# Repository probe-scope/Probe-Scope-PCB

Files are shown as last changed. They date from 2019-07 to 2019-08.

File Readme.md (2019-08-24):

# Probe-Scope PCB

This is the repo for the Probe-Scope, it is licenced under the CERN Open Hardware Licence v1.2.

See more on our [project page!](https://hackaday.io/project/165964-60mhz-bandwidth-250msps-probe-scope)

# Schematic Overview

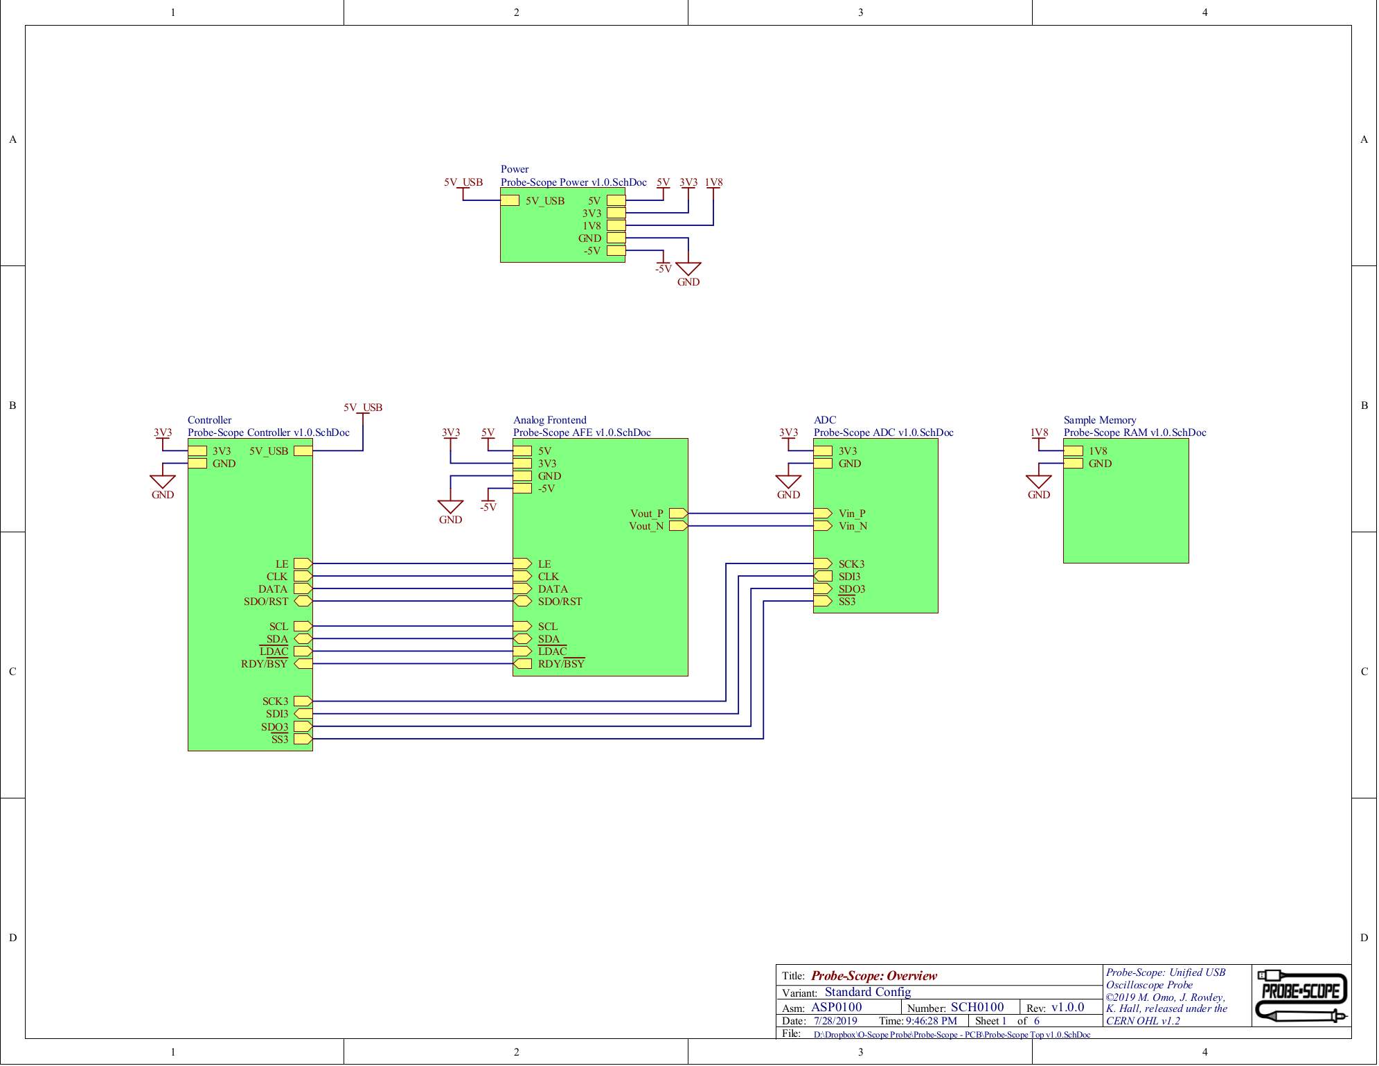
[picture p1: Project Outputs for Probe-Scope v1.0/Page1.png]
Page 1


# Final Assembled PCB

## Top

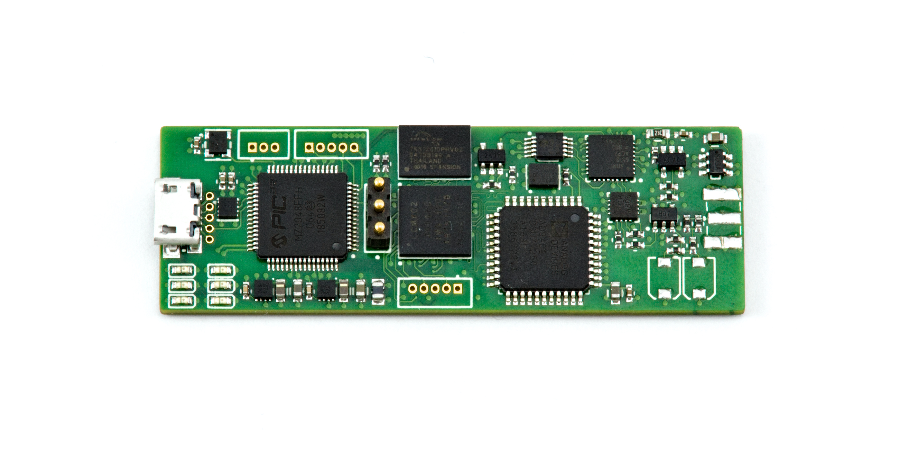
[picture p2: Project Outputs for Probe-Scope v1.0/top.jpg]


## Bottom

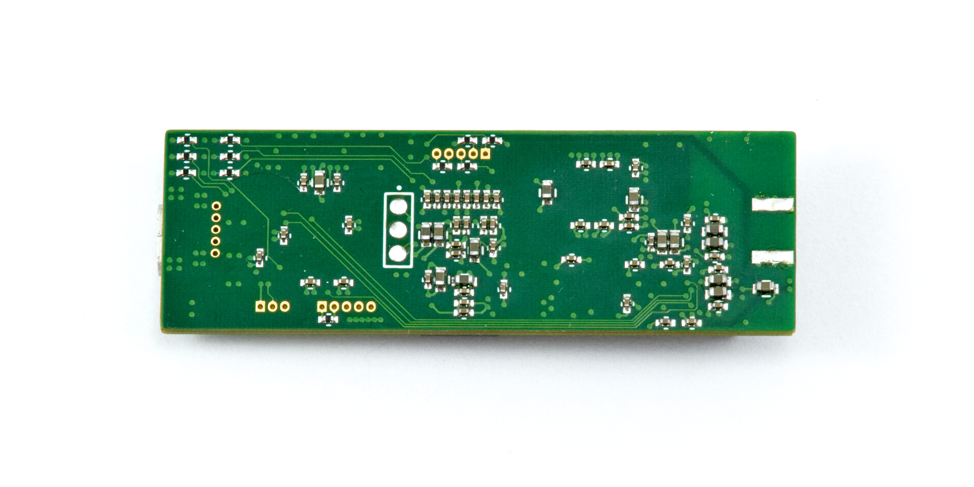
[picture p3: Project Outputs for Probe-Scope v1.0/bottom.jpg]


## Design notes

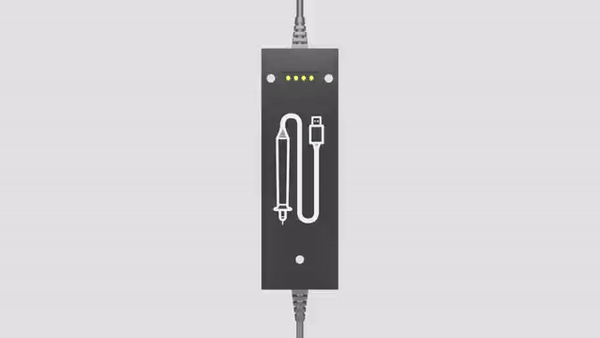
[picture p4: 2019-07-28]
Concept GIF.gif

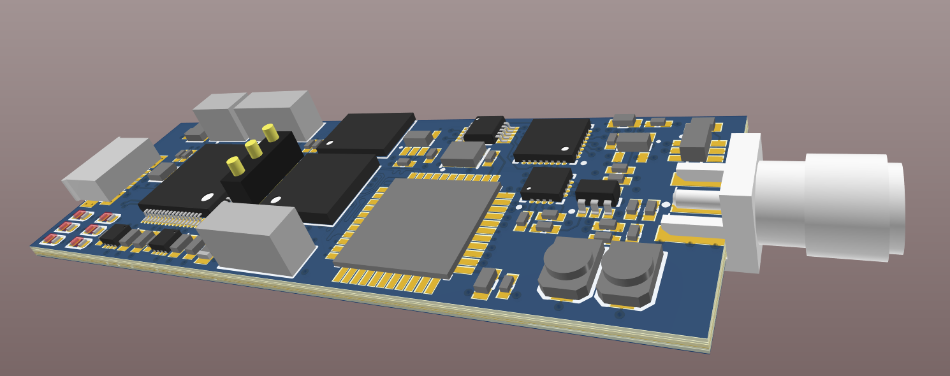
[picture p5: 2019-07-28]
3D Picture.PNG

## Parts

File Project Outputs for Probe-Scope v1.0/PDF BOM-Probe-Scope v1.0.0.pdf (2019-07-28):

BILL OF MATERIALS | Probe-Scope: Unified USB Oscilloscope Probe ©2019 M. Omo, J. Rowley, K. Hall Released under the CERN OHL v1.2
Designator | MANF | MANF_PN | Quantity | VENDOR | VENDOR_PN | P&V Description | Footprint | Comment
C1, C2, C3, C4, C5, C6, C7, C8, C9, C10, C11, C13, C14, C15, C16, C17, C18, C19, C20, C21, C22, C23, C26, C31, C32, C33, C34, C35, C36, C38, C40, C41, C42, C43, C44, C45, C46, C47, C48, C50, C51, C52, C54, C55, C56, C58, C59, C60, C64, C65, C66 | Samsung Electro-Mechanics | CL05B104KQ5NNNC | 51 | Digikey | 1276-1511-1-ND | Capacitor, Ceramic, 0.1uF, 6.3V, 10% Tol, 125C, X7R, 0402, SMD | 0402(1005) | 6.3V
C12 | Murata Electronics | GCM155C71A105KE38D | 1 | Digikey | 490-13409-1-ND | Capacitor, Ceramic, 1uF, 10V, 10% Tol, 125C, X7S, 0402, SMD | 0402(1005) | 10V
C24, C25, C27, C28, C29, C30, C37, C39, C49, C53, C57, C61, C62, C63, C67, C68, C70, C72, C73 | Samsung Electro-Mechanics | CL10A106MA8NRNC | 19 | Digikey | 1276-1869-1-ND | Capacitor, Ceramic, 10uF, 25V, 20% Tol, 85C, X5R, 0603, SMD | 0603(1608) | 25V
C69, C71 | Samsung Electro-Mechanics | CL05B561KB5NNNC | 2 | Digikey | 1276-1577-1-ND | Capacitor, Electrolytic, 560p, 50V, 10% Tol, 0402, SMD | 0402(1005) | Cap
D1, D2, D3, D5, D6, D7 | OSRAM | LG L29K-F2J1-24 | 6 | Digikey | 475-1193-1-ND | LED, 1.7V, 0.02A, Green, 570nm, diffused, 0603, SMD | 0603(1608) LED | Green
L1, L2 | Taiyo Yuden | MCKK1608T1R0MN | 2 | Digikey | 587-5973-1-ND | Inductor, Shielded, 1u, 1.3A, 0.123 Ohms, 0603, SMD | 0603(1608) | Inductor
L3 | TDK | MMZ2012Y121B | 1 | Digikey | 445-2196-1-ND | Inductor, Ferrite Bead, 0.8A, 120 Ohm at 100MHz, Effective from 80MHz To 400MHz, Y Material, 0805, SMD | 0805(2012) | Ferrite Bead Y
P3 | Amphenol FCI | 10118192-0002LF | 1 | Digikey | 609-5379-1-ND | Connector, USB, 5 Positions, Female, 0.026" Spacing, 1.8A, 100V, USB - micro B USB 2.0 Receptacle Connector 5 Position Surface Mount, Right Angle, Without Flange, SMD | USB Micro B ZX62 | Micro USB
P7 | Prec-Dip | 811-SS-003-30-002101 | 1 | DigiKey | 1212-1561-ND | | POGO_PIN S_3 | Pogo Pins
R1, R4, R5, R6, R9, R10, R11 | Yageo | RC0402FR-07100RL | 7 | Digikey | 311-100LRCT-ND | Resistor, Thick Film, 100 Ohms, 0.0625W, 1% Tol, 100V, 0402, SMD | 0402(1005) | Res1
R2, R3, R7 | Stackpole Electronics | RMCF0402FT10K0 | 3 | Digikey | RMCF0402FT10K0CT-ND | Resistor, Thick Film, 10k Ohms, 0.0625W, 1% Tol, 100V, 0402, SMD | 0402(1005) | 0.1% 25ppm
R8 | Panasonic | ERJ-3EKF1692V | 1 | Digikey | P16.9KHCT-ND | Resistor, Thick Film, 16.9k Ohms, 0.1W, 1% Tol, 0603, SMD | 0603(1608) | Res1
R12, R13, R14, R15 | Yageo | RC0402FR-074K99L | 4 | Digikey | 311-4.99KLRCT-ND | Resistor, Thick Film, 4.99k Ohms, 0.063W, 1% Tol, RES SMD 4.99K OHM 1% 1/16W 0402, 0402, SMD | 0402(1005) | Res1
2019-07-21 | 1/2 | Probe-Scope v1.0.0

BILL OF MATERIALS | Probe-Scope: Unified USB Oscilloscope Probe ©2019 M. Omo, J. Rowley, K. Hall Released under the CERN OHL v1.2
R16, R17 | Stackpole Electronics | RMCF0402FT2K32 | 2 | Digikey | RMCF0402FT2K32CT-ND
| | | Resistor, Thick Film, 2.32k Ohms, 0.0625W, 1% Tol, 2.32 kOhms ±1% 0.063W, 1/16W Chip Resistor 0402 (1005 Metric) Automotive AEC-Q200 Thick Film, 0402, SMD | 0402(1005) | Res1
R18, R19, R20, R21, R22, R23 | Yageo | RC0402FR-071KL | 6 | Digikey | 311-1.00KLRCT-ND | Resistor, Thick Film, 1k Ohms, 0.063W, 1% Tol, 1kOhm, 1%, 1/16W, Thick Film, 0402, SMD | 0402(1005) | 1k
R24 | Vishay Dale | CRCW040210M0FKEDC | 1 | Digikey | 541-4068-1-ND | Resistor, Thick Film, 10M Ohms, 0.063W, 1% Tol, 0402, SMD | 0402(1005) | Res1
R25 | Vishay Dale | CRCW0402680KJNED | 1 | Digikey | 541-680KJCT-ND | Resistor, Thick Film, 680k Ohms, 0.063W, 1% Tol, 0402, SMD | 0402(1005) | Res1
R26 | Vishay Dale | CRCW0402330KFKEDHP | 1 | Digikey | 541-330KYCT-ND | Resistor, Thick Film, 330k Ohms, 0.2W, 1% Tol, 0402, SMD | 0402(1005) | Res1
R27, R28 | Vishay Dale | CRCW040228K0FKED | 2 | Digikey | 541-28.0KLCT-ND | Resistor, Thick Film, 28k Ohms, 0.063W, 1% Tol, 0402, SMD | 0402(1005) | Res1
U1 | Analog Devices Inc. | AD9481BSUZ-250 | 1 | DigiKey | AD9481BSUZ-250-ND | | QFP80P12 00X1200X1 20-44N | AD9481BSUZ-250
U2 | Lattice Semiconductor | LCMXO2-4000HC-4MG132C | 1 | DigiKey | 220-1458-ND | | 132_Ball_c sBGA_Mac hXO2 | LCMXO2-4000
U3 | Microchip Technology | PIC32MZ2048EFH064-I/PT | 1 | DigiKey | PIC32MZ2048EFH064-I/PT-ND | | TSQFP50P 1200X1200 X120-64L | PIC32MZ2048EFH064
U4 | Cypress | S70KS1281DPBHV020 | 1 | DigiKey | 2015-S70KS1281DPBHV020-ND | | Cypress-VAA024 | S70KS128
U5 | Microchip Technology | DSC1103CI3-250.0000 | 1 | Mouser | 579-1103CI32500000 | | MCHP_H5 A | DSC1103
U6 | Microchip | MIC23050-SYML-TR | 1 | Digikey | 576-3351-1-ND | | MCP_8_M LF | MIC23050_3V
U7 | Microchip | DSC6011JI1A-024.0000 | 1 | Digikey | DSC6011JI1A-024.0000-ND | IC, Oscillator, 24MHz XO (Standard) CMOD Oscillator, 1.71-3.63V, Standby (Power Down), 4-SMD, SMD | DSC60xxC | 24MHz XO
U8 | On Semiconductor | EMI2121MTTAG | 1 | Digikey | EMI2121MTTAGOSCT-ND | IC, Channel Protector, USB Common-Mode Filter and ESD Protection, WDFN-8, SMD | EMI2121 | EMI2121
U9 | Microchip | MIC23050-GYML-TR | 1 | Digikey | 576-2974-1-ND | | MCP_8_M LF | MIC23050_1V8
U10, U12 | Microchip | MCP6H01T-E/OT | 2 | Digikey | MCP6H01T-E/OTCT-ND | IC, Op Amp, 3.5V to 16V, SOT-23-5, SMD | SOT23-5 | MCP6H01
U11 | Analog Devices Inc. | AD8055ARTZ-REEL7 | 1 | DigiKey | AD8055ARTZ-REEL7CT-ND | | SOT95P28 0X145-5L | AD8055
U13 | Analog Devices Inc. | ADA4932-1YCPZ-R7 | 1 | DigiKey | ADA4932-1YCPZ-R7CT-ND | | QFN50P30 0X300X80_ HS-17L | ADA4932-1
U14 | Analog Devices Inc. | ADRF6518ACPZ-R7 | 1 | DigiKey | ADRF6518ACPZ-R7TR-ND | | QFN50P50 0X500X80_ HS-33L | ADRF6518
U15 | Microchip Technology | MCP4728T-E/UN | 1 | DigiKey | MCP4728T-E/UNCT-ND | | MSOP-10 | MCP4728
U16 | Texas Instruments | LM2664M6X/NOPB | 1 | DigiKey | LM2664M6X/NOPBCT-ND | | SOT95P28 0X145-6N | LM2664
2019-07-21 | 2/2 | Probe-Scope v1.0.0

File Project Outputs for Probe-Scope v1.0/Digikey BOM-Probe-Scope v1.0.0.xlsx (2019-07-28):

Comment | Designator | Footprint | MANF | MANF_PN | P&V Description | Quantity | VENDOR | VENDOR_PN
6.3V | C1, C2, C3, C4, C5, C6, C7, C8, C9, C10, C11, C13, C14, C15, C16, C17, C18, C19, C20, C21, C22, C23, C26, C31, C32, C33, C34, C35, C36, C38, C40, C41, C42, C43, C44, C45, C46, C47, C48, C50, C51, C52, C54, C55, C56, C58, C59, C60, C64, C65, C66 | 0402(1005) | Samsung Electro-Mechanics | CL05B104KQ5NNNC | Capacitor, Ceramic, 0.1uF, 6.3V, 10% Tol, 125C, X7R, 0402, SMD | 51 | Digikey | 1276-1511-1-ND
10V | C12 | 0402(1005) | Murata Electronics | GCM155C71A105KE38D | Capacitor, Ceramic, 1uF, 10V, 10% Tol, 125C, X7S, 0402, SMD | 1 | Digikey | 490-13409-1-ND
25V | C24, C25, C27, C28, C29, C30, C37, C39, C49, C53, C57, C61, C62, C63, C67, C68, C70, C72, C73 | 0603(1608) | Samsung Electro-Mechanics | CL10A106MA8NRNC | Capacitor, Ceramic, 10uF, 25V, 20% Tol, 85C, X5R, 0603, SMD | 19 | Digikey | 1276-1869-1-ND
Cap | C69, C71 | 0402(1005) | Samsung Electro-Mechanics | CL05B561KB5NNNC | Capacitor, Electrolytic, 560p, 50V, 10% Tol, 0402, SMD | 2 | Digikey | 1276-1577-1-ND
Green | D1, D2, D3, D5, D6, D7 | 0603(1608) LED | OSRAM | LG L29K-F2J1-24 | LED, 1.7V, 0.02A, Green, 570nm, diffused, 0603, SMD | 6 | Digikey | 475-1193-1-ND
Inductor | L1, L2 | 0603(1608) | Taiyo Yuden | MCKK1608T1R0MN | Inductor, Shielded, 1u, 1.3A, 0.123 Ohms, 0603, SMD | 2 | Digikey | 587-5973-1-ND
Ferrite Bead Y | L3 | 0805(2012) | TDK | MMZ2012Y121B | Inductor, Ferrite Bead, 0.8A, 120 Ohm at 100MHz, Effective from 80MHz To 400MHz, Y Material, 0805, SMD | 1 | Digikey | 445-2196-1-ND
Micro USB | P3 | USB Micro B ZX62 | Amphenol FCI | 10118192-0002LF | Connector, USB, 5 Positions, Female, 0.026" Spacing, 1.8A, 100V, USB - micro B USB 2.0 Receptacle Connector 5 Position Surface Mount, Right Angle, Without Flange, SMD | 1 | Digikey | 609-5379-1-ND
Pogo Pins | P7 | POGO_PINS_3 | Prec-Dip | 811-SS-003-30-002101 |  | 1 | DigiKey | 1212-1561-ND
Res1 | R1, R4, R5, R6, R9, R10, R11 | 0402(1005) | Yageo | RC0402FR-07100RL | Resistor, Thick Film, 100 Ohms, 0.0625W, 1% Tol, 100V, 0402, SMD | 7 | Digikey | 311-100LRCT-ND
0.1% 25ppm | R2, R3, R7 | 0402(1005) | Stackpole Electronics | RMCF0402FT10K0 | Resistor, Thick Film, 10k Ohms, 0.0625W, 1% Tol, 100V, 0402, SMD | 3 | Digikey | RMCF0402FT10K0CT-ND
Res1 | R8 | 0603(1608) | Panasonic | ERJ-3EKF1692V | Resistor, Thick Film, 16.9k Ohms, 0.1W, 1% Tol, 0603, SMD | 1 | Digikey | P16.9KHCT-ND
Res1 | R12, R13, R14, R15 | 0402(1005) | Yageo | RC0402FR-074K99L | Resistor, Thick Film, 4.99k Ohms, 0.063W, 1% Tol, RES SMD 4.99K OHM 1% 1/16W 0402, 0402, SMD | 4 | Digikey | 311-4.99KLRCT-ND
Res1 | R16, R17 | 0402(1005) | Stackpole Electronics | RMCF0402FT2K32 | Resistor, Thick Film, 2.32k Ohms, 0.0625W, 1% Tol, 2.32 kOhms ±1% 0.063W, 1/16W Chip Resistor 0402 (1005 Metric) Automotive AEC-Q200 Thick Film, 0402, SMD | 2 | Digikey | RMCF0402FT2K32CT-ND
1k | R18, R19, R20, R21, R22, R23 | 0402(1005) | Yageo | RC0402FR-071KL | Resistor, Thick Film, 1k Ohms, 0.063W, 1% Tol, 1kOhm, 1%, 1/16W, Thick Film, 0402, SMD | 6 | Digikey | 311-1.00KLRCT-ND
Res1 | R24 | 0402(1005) | Vishay Dale | CRCW040210M0FKEDC | Resistor, Thick Film, 10M Ohms, 0.063W, 1% Tol, 0402, SMD | 1 | Digikey | 541-4068-1-ND
Res1 | R25 | 0402(1005) | Vishay Dale | CRCW0402680KJNED | Resistor, Thick Film, 680k Ohms, 0.063W, 1% Tol, 0402, SMD | 1 | Digikey | 541-680KJCT-ND
Res1 | R26 | 0402(1005) | Vishay Dale | CRCW0402330KFKEDHP | Resistor, Thick Film, 330k Ohms, 0.2W, 1% Tol, 0402, SMD | 1 | Digikey | 541-330KYCT-ND
Res1 | R27, R28 | 0402(1005) | Vishay Dale | CRCW040228K0FKED | Resistor, Thick Film, 28k Ohms, 0.063W, 1% Tol, 0402, SMD | 2 | Digikey | 541-28.0KLCT-ND
AD9481BSUZ-250 | U1 | QFP80P1200X1200X120-44N | Analog Devices Inc. | AD9481BSUZ-250 |  | 1 | DigiKey | AD9481BSUZ-250-ND
LCMXO2-4000 | U2 | 132_Ball_csBGA_MachXO2 | Lattice Semiconductor | LCMXO2-4000HC-4MG132C |  | 1 | DigiKey | 220-1458-ND
PIC32MZ2048EFH064 | U3 | TSQFP50P1200X1200X120-64L | Microchip Technology | PIC32MZ2048EFH064-I/PT |  | 1 | DigiKey | PIC32MZ2048EFH064-I/PT-ND
S70KS128 | U4 | Cypress-VAA024 | Cypress | S70KS1281DPBHV020 |  | 1 | DigiKey | 2015-S70KS1281DPBHV020-ND
DSC1103 | U5 | MCHP_H5A | Microchip Technology | DSC1103CI3-250.0000 |  | 1 | Mouser | 579-1103CI32500000
MIC23050_3V | U6 | MCP_8_MLF | Microchip | MIC23050-SYML-TR |  | 1 | Digikey | 576-3351-1-ND
24MHz XO | U7 | DSC60xxC | Microchip | DSC6011JI1A-024.0000 | IC, Oscillator, 24MHz XO (Standard) CMOD Oscillator, 1.71-3.63V, Standby (Power Down), 4-SMD, SMD | 1 | Digikey | DSC6011JI1A-024.0000-ND
EMI2121 | U8 | EMI2121 | On Semiconductor | EMI2121MTTAG | IC, Channel Protector, USB Common-Mode Filter and ESD Protection, WDFN-8, SMD | 1 | Digikey | EMI2121MTTAGOSCT-ND
MIC23050_1V8 | U9 | MCP_8_MLF | Microchip | MIC23050-GYML-TR |  | 1 | Digikey | 576-2974-1-ND
MCP6H01 | U10, U12 | SOT23-5 | Microchip | MCP6H01T-E/OT | IC, Op Amp, 3.5V to 16V, SOT-23-5, SMD | 2 | Digikey | MCP6H01T-E/OTCT-ND
AD8055 | U11 | SOT95P280X145-5L | Analog Devices Inc. | AD8055ARTZ-REEL7 |  | 1 | DigiKey | AD8055ARTZ-REEL7CT-ND
ADA4932-1 | U13 | QFN50P300X300X80_HS-17L | Analog Devices Inc. | ADA4932-1YCPZ-R7 |  | 1 | DigiKey | ADA4932-1YCPZ-R7CT-ND
ADRF6518 | U14 | QFN50P500X500X80_HS-33L | Analog Devices Inc. | ADRF6518ACPZ-R7 |  | 1 | DigiKey | ADRF6518ACPZ-R7TR-ND
MCP4728 | U15 | MSOP-10 | Microchip Technology | MCP4728T-E/UN |  | 1 | DigiKey | MCP4728T-E/UNCT-ND
LM2664 | U16 | SOT95P280X145-6N | Texas Instruments | LM2664M6X/NOPB |  | 1 | DigiKey | LM2664M6X/NOPBCT-ND

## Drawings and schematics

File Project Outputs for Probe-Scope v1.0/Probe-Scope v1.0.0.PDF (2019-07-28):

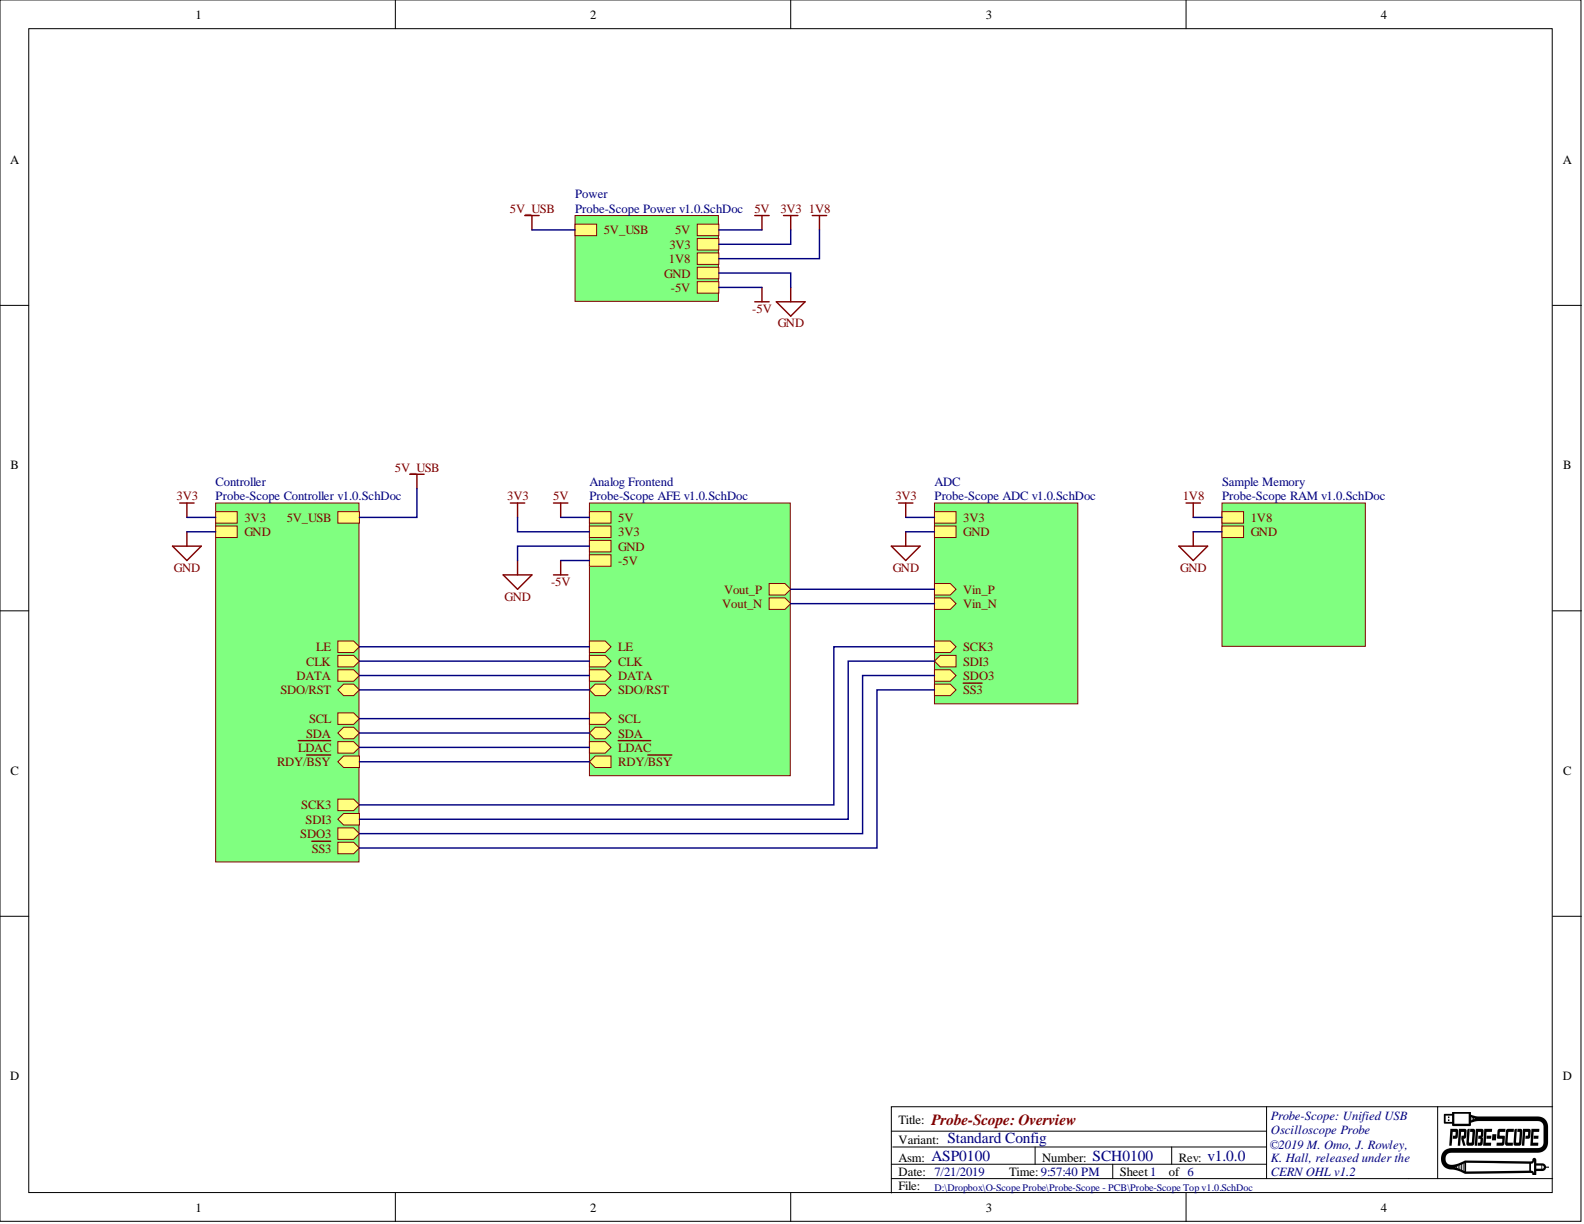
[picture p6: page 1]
CERN OHL v1.2; Probe-Scope: Overview; SCH0100; Title:; Asm:; Number:; Date: File:; Rev:; Time:; Sheet; ASP0100; Variant: Standard Config; ©2019 M. Omo, J. Rowley,; Vout_N; RDY/BSY; CLK; Vout_P; GND; LDAC; SDA; DATA; SDO/RST; SCL; Vin_P Vin_N; 3V3 GND; SDO3 SS3; SDI3; SCK3; ADC; Probe-Scope ADC v1.0.SchDoc; Sample Memory; Probe-Scope RAM v1.0.SchDoc; SDO3; 5V_USB; Controller; Probe-Scope Controller v1.0.SchDoc; 1V8 GND

Power
Probe-Scope Power v1.0.SchDoc 5V 3V3

Analog Frontend
Probe-Scope AFE v1.0.SchDoc

Probe-Scope: Unified USB
Oscilloscope Probe

K. Hall, released under the

D:\Dropbox\O-Scope Probe\Probe-Scope - PCB\Probe-Scope Top v1.0.SchDoc

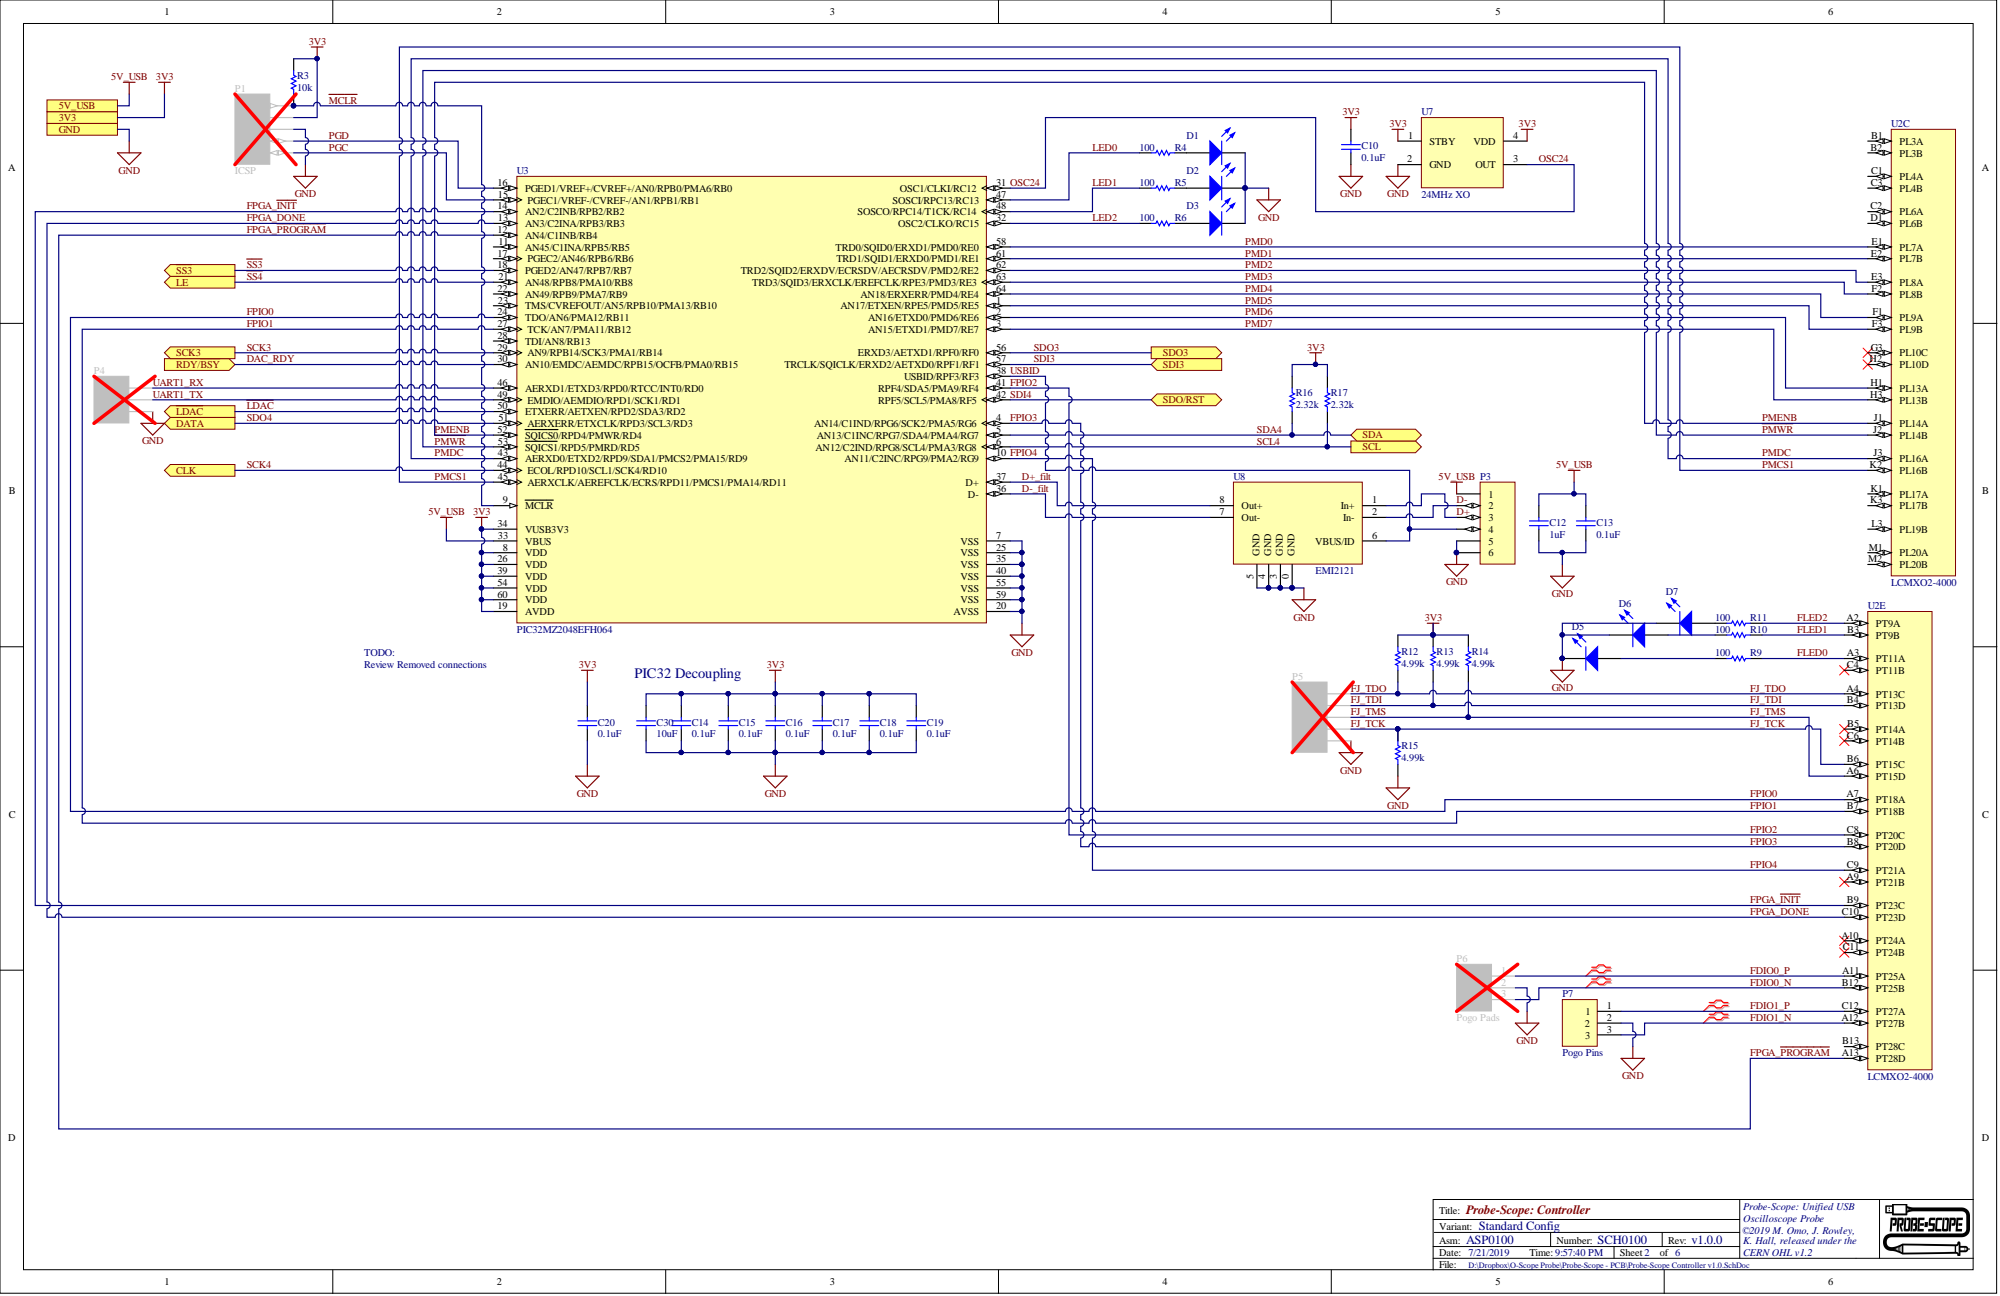
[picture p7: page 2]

Probe-Scope: Unified USB

D:\Dropbox\O-Scope Probe\Probe-Scope - PCB\Probe-Scope Controller v1.0.SchDoc

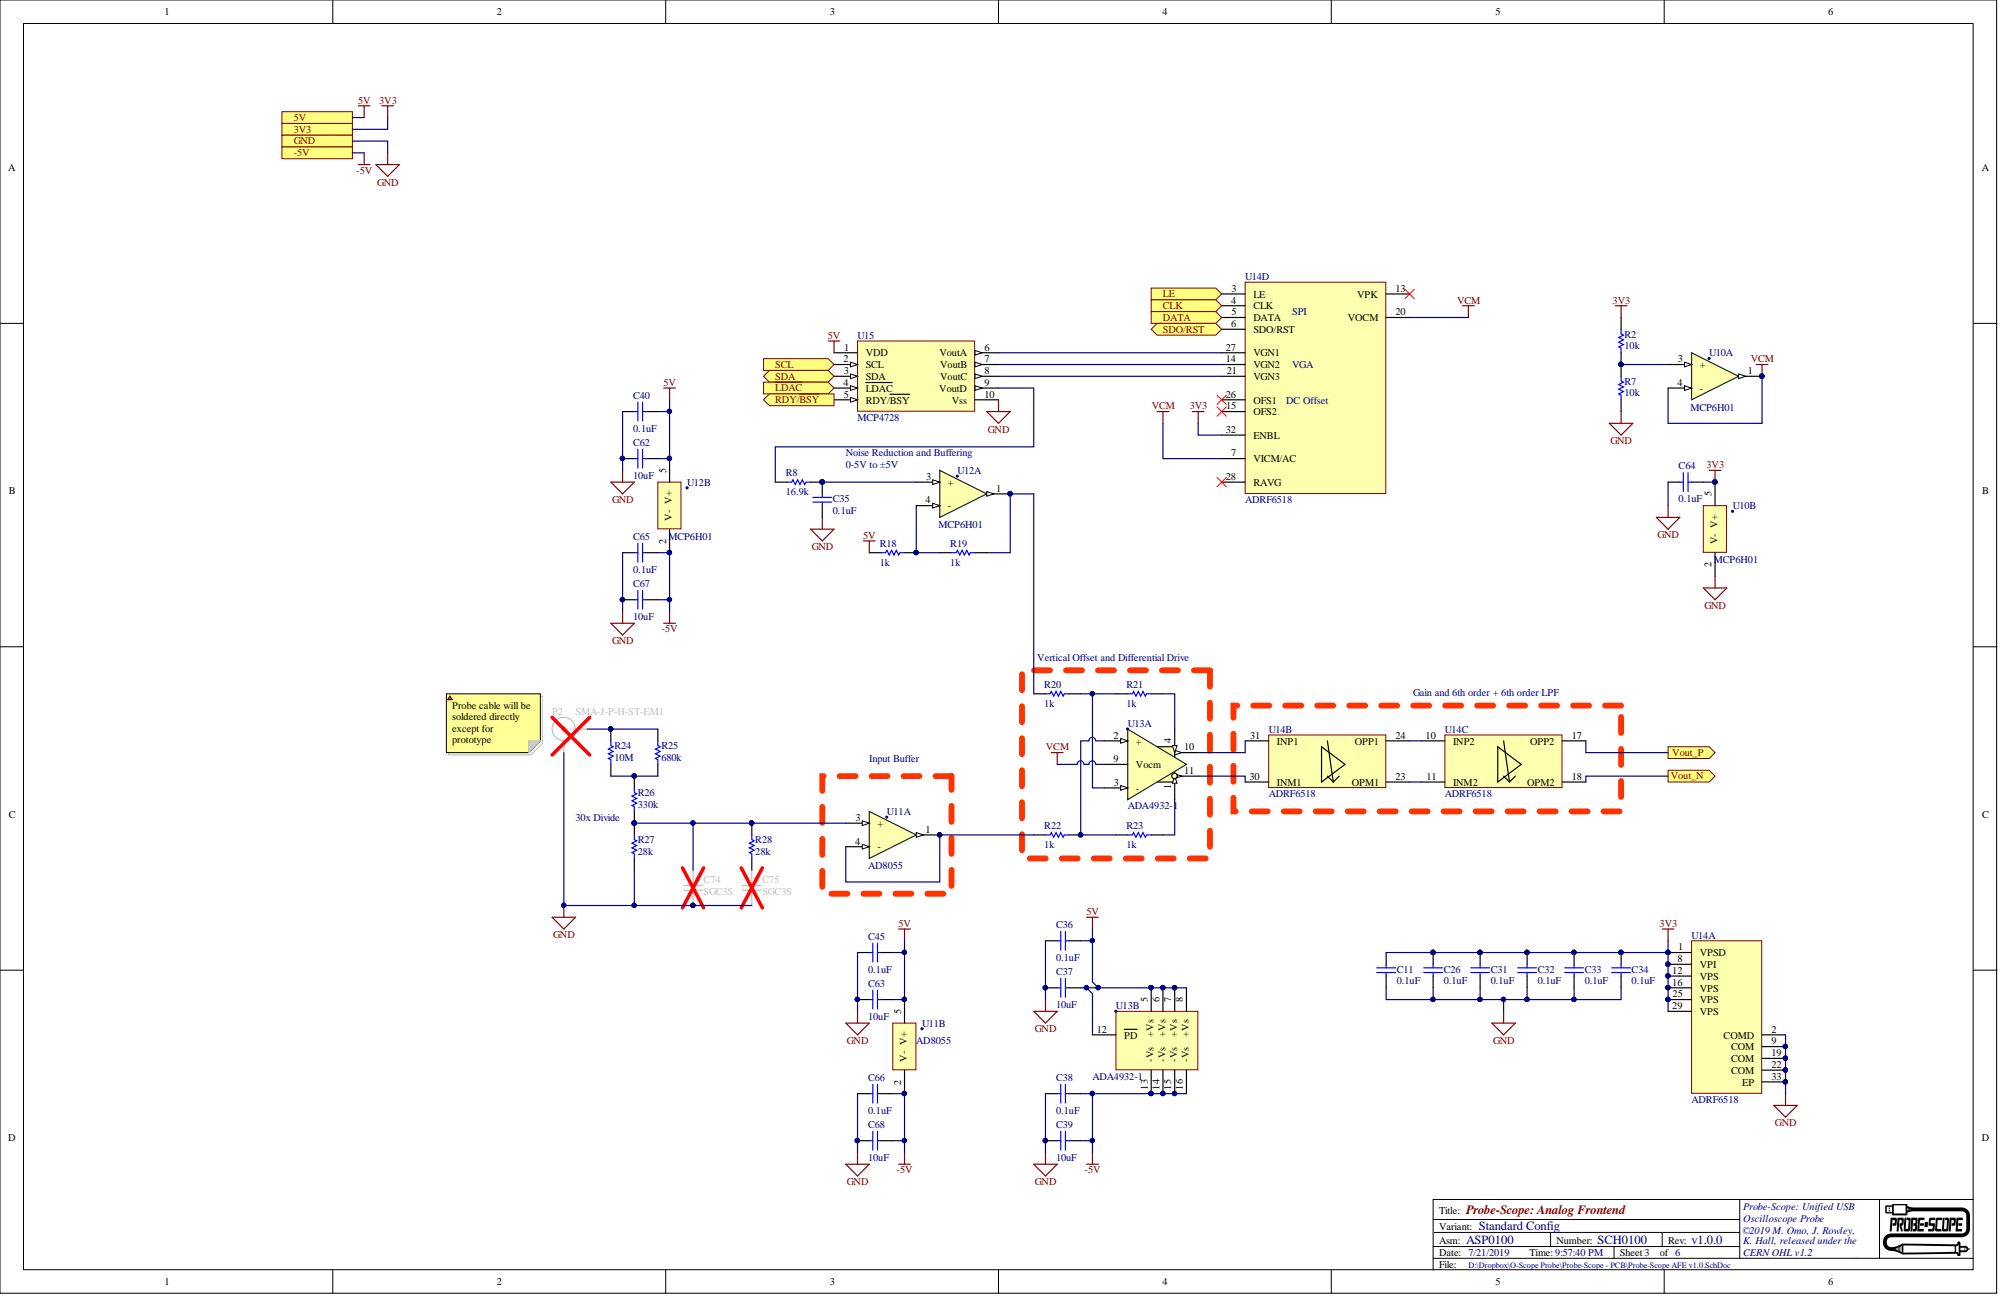
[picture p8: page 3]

Noise Reduction and Buffering

Vertical Offset and Differential Drive

Gain and 6th order + 6th order LPF

Probe cable will be
soldered directly
except for
prototype

Probe-Scope: Analog Frontend

Probe-Scope: Unified USB

D:\Dropbox\O-Scope Probe\Probe-Scope - PCB\Probe-Scope AFE v1.0.SchDoc

# 3V3 GND

# 3V3 GND

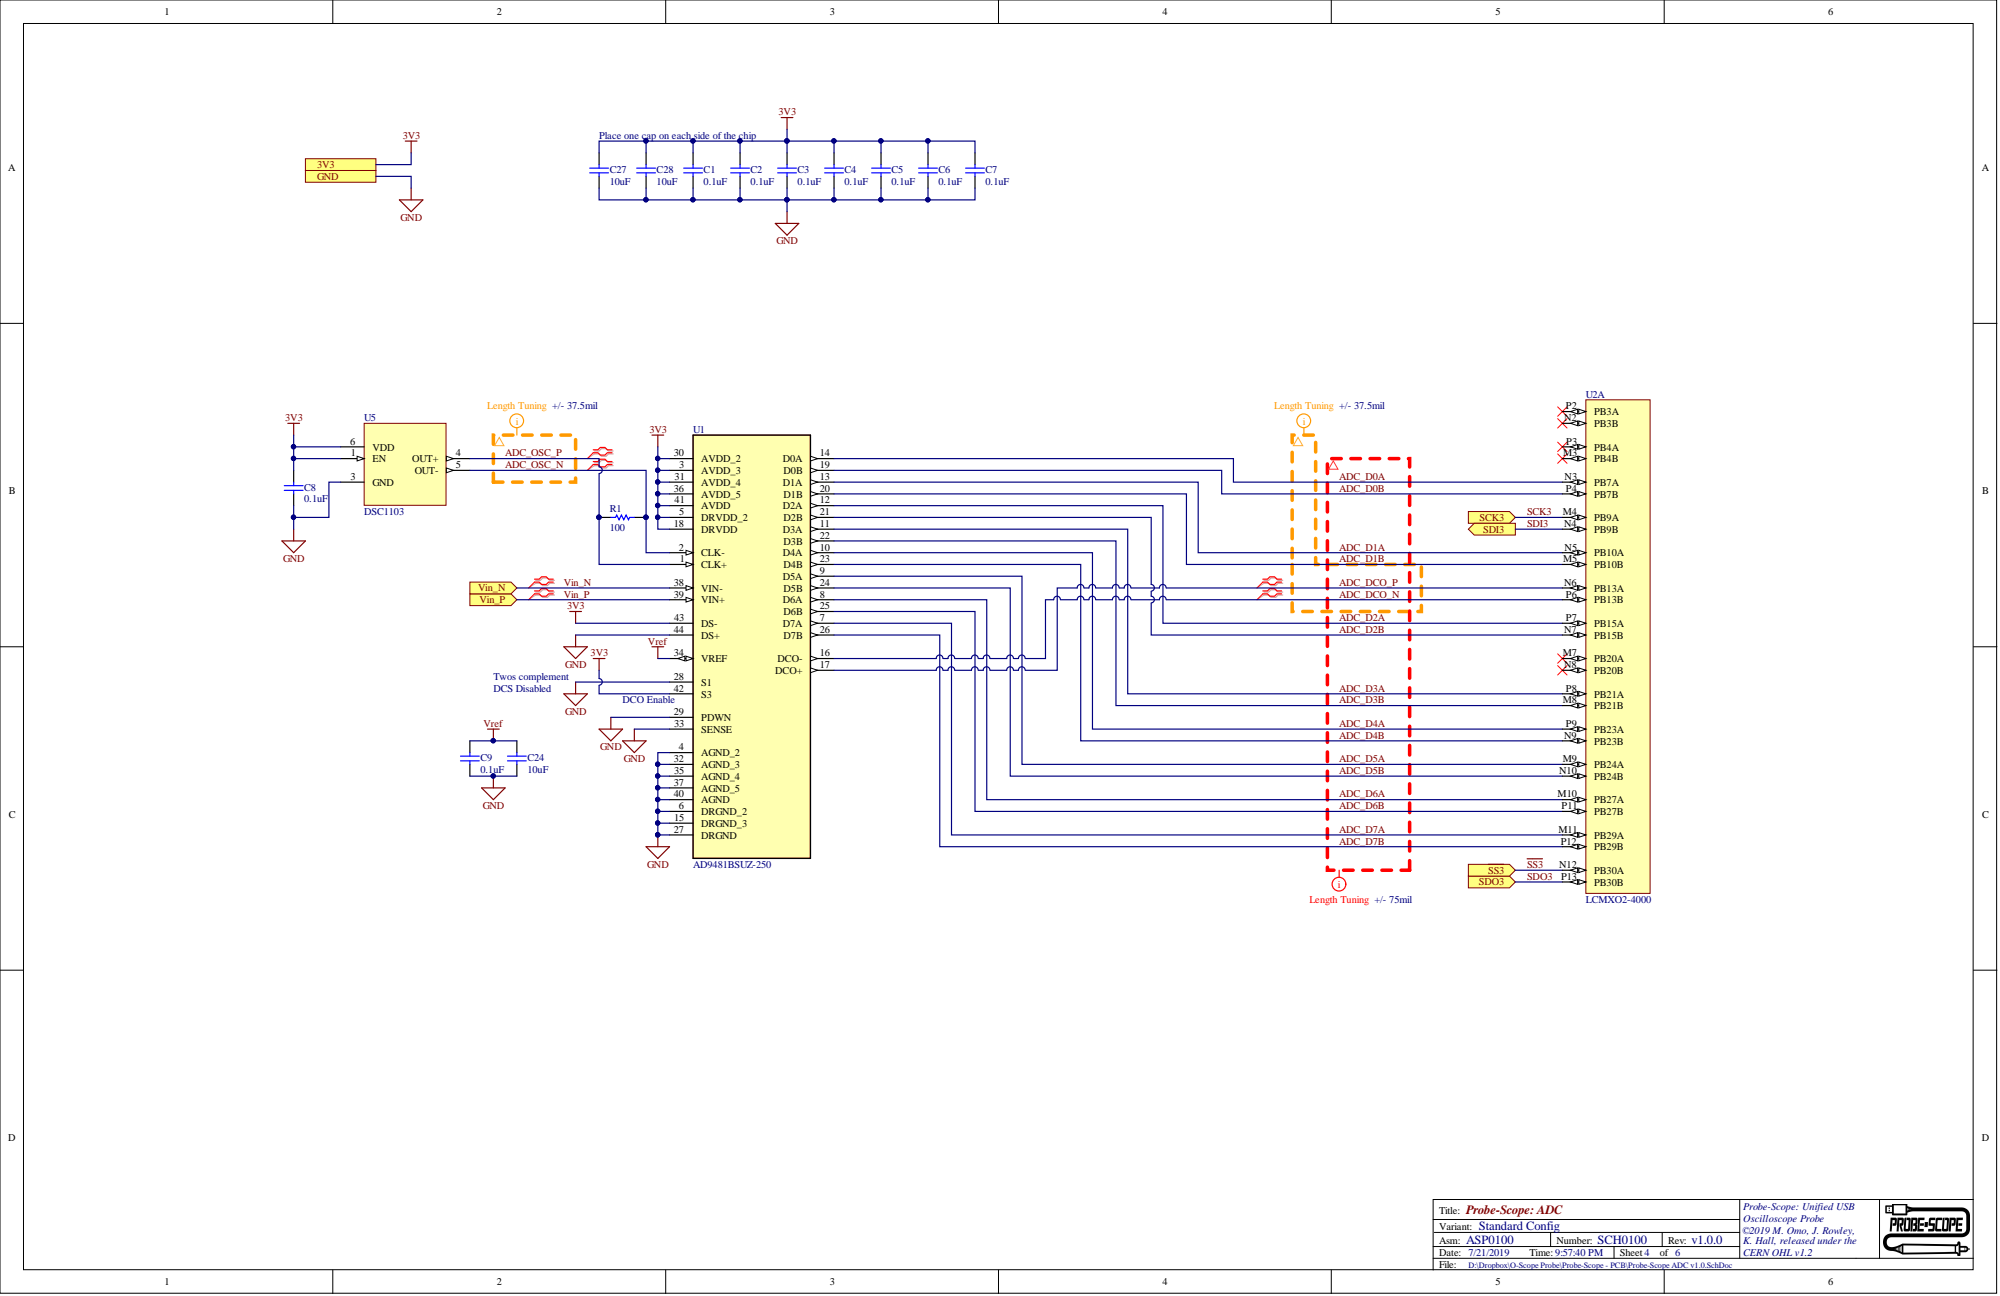
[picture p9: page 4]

# 1V8 GND

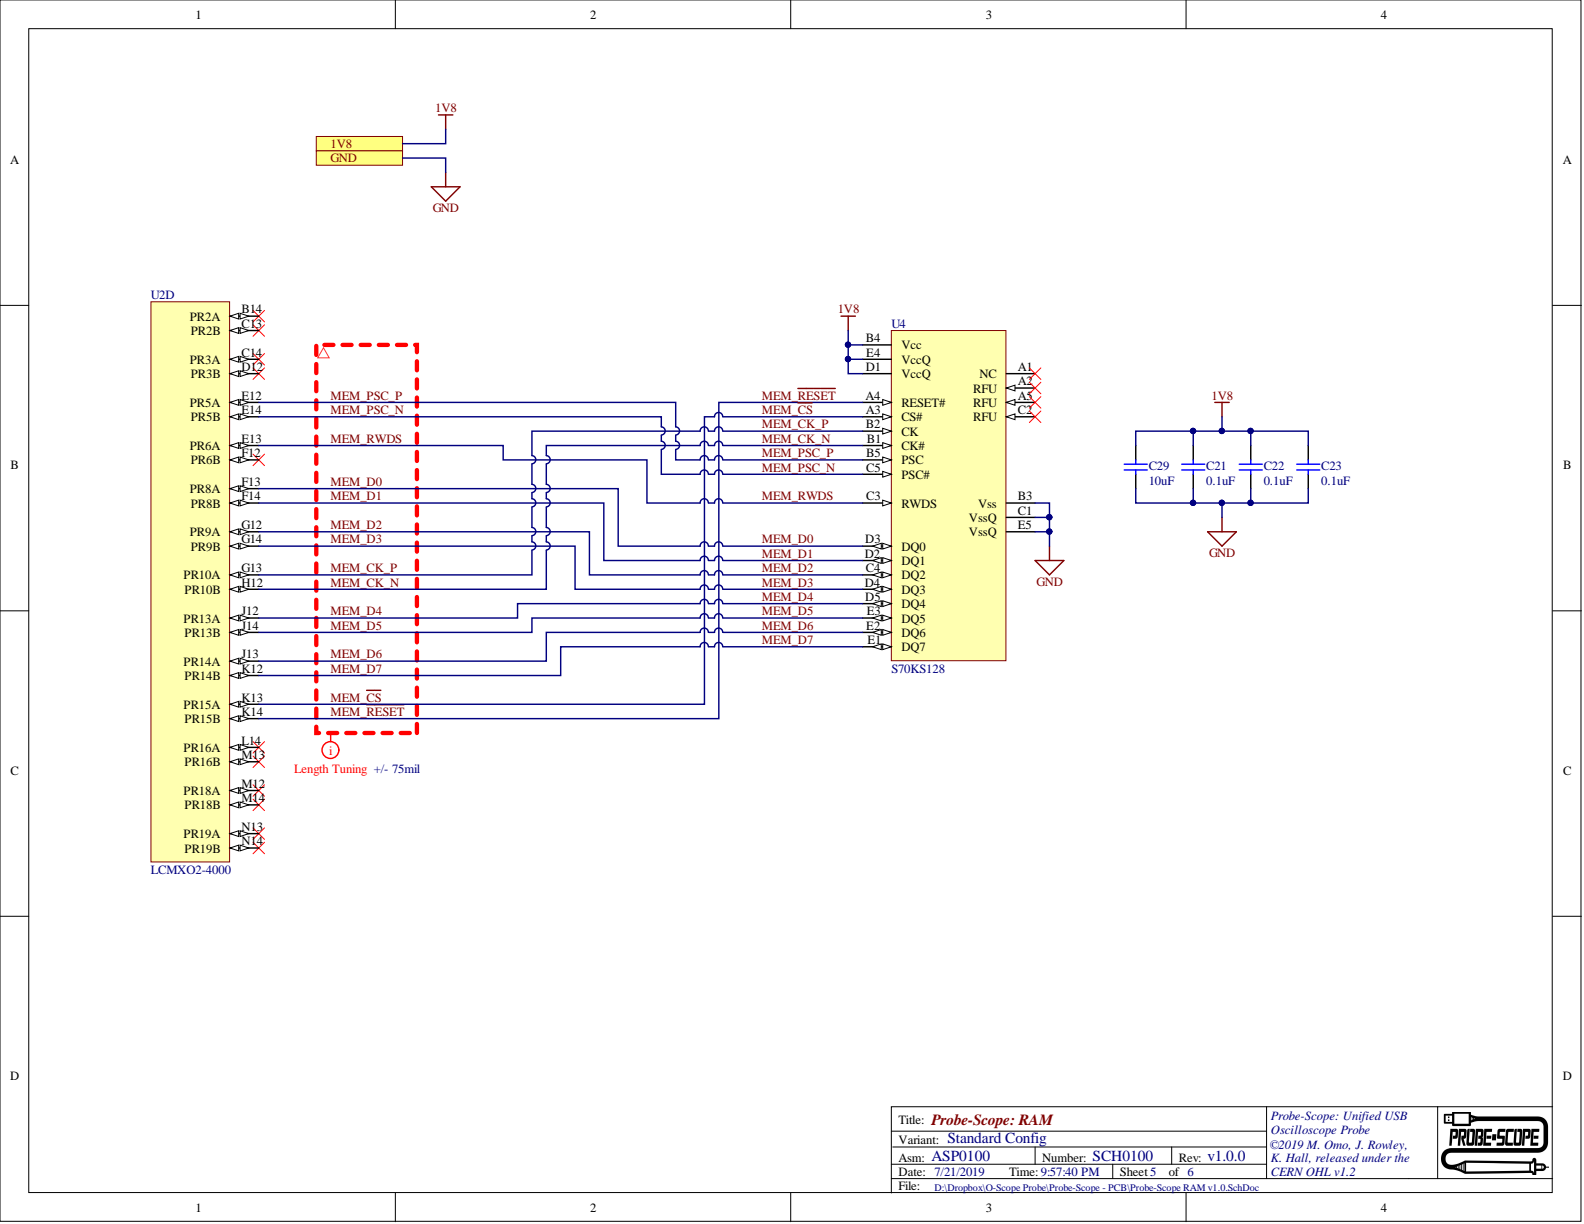
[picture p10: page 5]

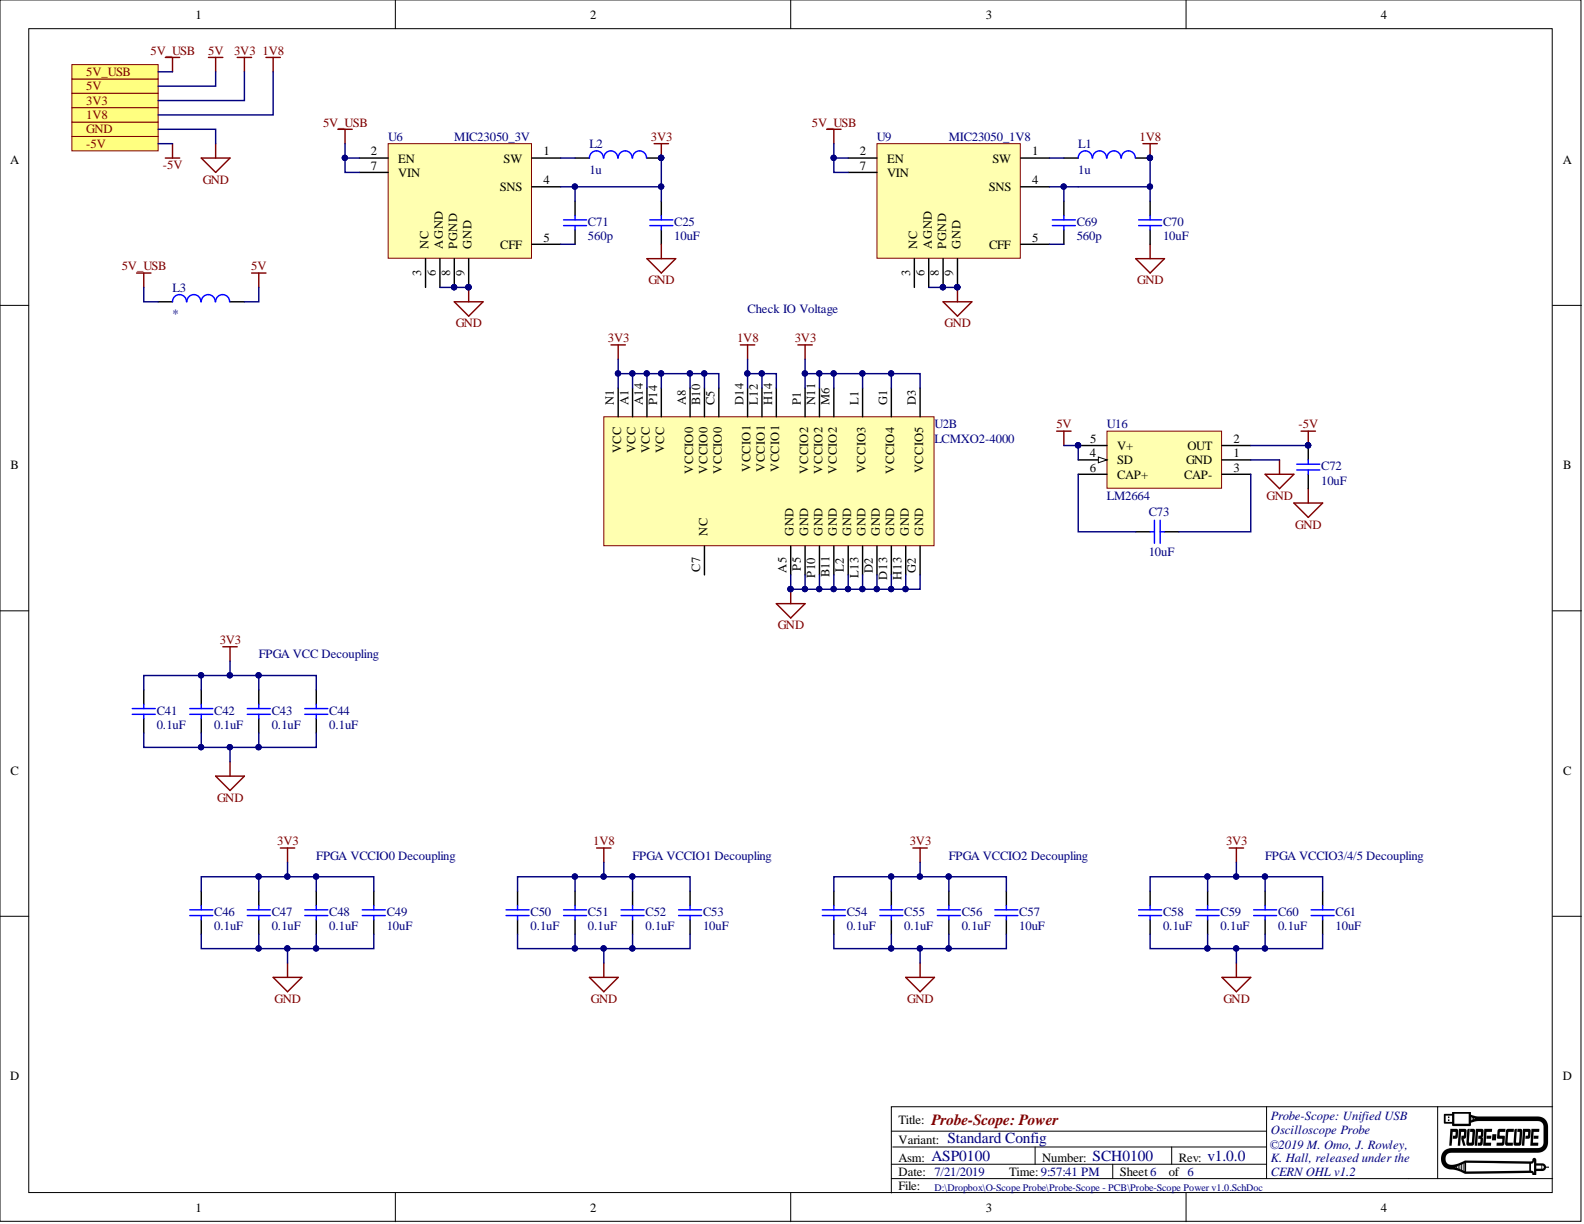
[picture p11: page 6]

Probe-Scope: Unified USB

D:\Dropbox\O-Scope Probe\Probe-Scope - PCB\Probe-Scope Power v1.0.SchDoc

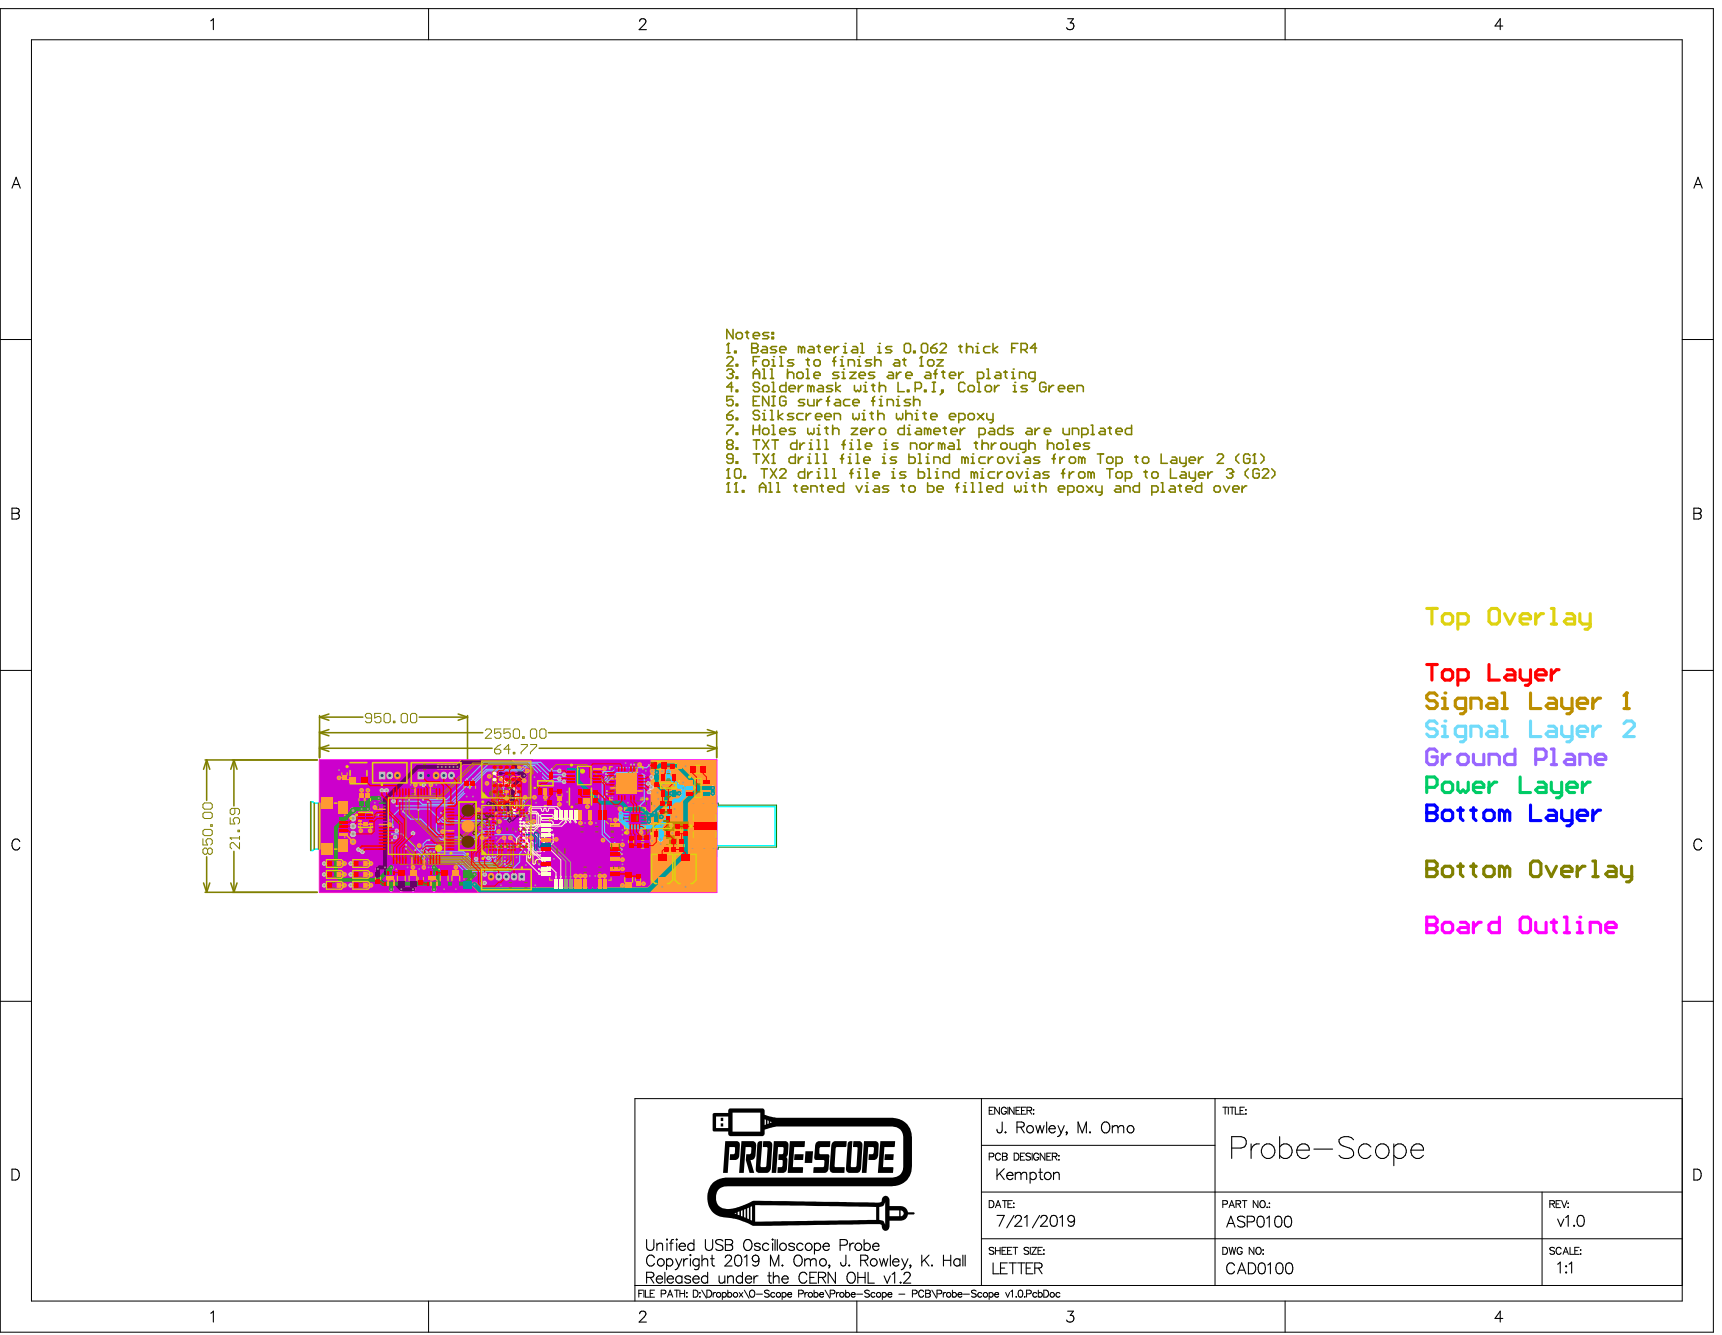
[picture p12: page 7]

BILL OF MATERIALS | Probe-Scope: Unified USB Oscilloscope Probe ©2019 M. Omo, J. Rowley, K. Hall Released under the CERN OHL v1.2
Designator | MANF | MANF_PN | Quantity | VENDOR | VENDOR_PN | P&V Description | Footprint | Comment
C1, C2, C3, C4, C5, C6, C7, C8, C9, C10, C11, C13, C14, C15, C16, C17, C18, C19, C20, C21, C22, C23, C26, C31, C32, C33, C34, C35, C36, C38, C40, C41, C42, C43, C44, C45, C46, C47, C48, C50, C51, C52, C54, C55, C56, C58, C59, C60, C64, C65, C66 | Samsung Electro-Mechanics | CL05B104KQ5NNNC | 51 | Digikey | 1276-1511-1-ND | Capacitor, Ceramic, 0.1uF, 6.3V, 10% Tol, 125C, X7R, 0402, SMD | 0402(1005) | 6.3V
C12 | Murata Electronics | GCM155C71A105KE38D | 1 | Digikey | 490-13409-1-ND | Capacitor, Ceramic, 1uF, 10V, 10% Tol, 125C, X7S, 0402, SMD | 0402(1005) | 10V
C24, C25, C27, C28, C29, C30, C37, C39, C49, C53, C57, C61, C62, C63, C67, C68, C70, C72, C73 | Samsung Electro-Mechanics | CL10A106MA8NRNC | 19 | Digikey | 1276-1869-1-ND | Capacitor, Ceramic, 10uF, 25V, 20% Tol, 85C, X5R, 0603, SMD | 0603(1608) | 25V
C69, C71 | Samsung Electro-Mechanics | CL05B561KB5NNNC | 2 | Digikey | 1276-1577-1-ND | Capacitor, Electrolytic, 560p, 50V, 10% Tol, 0402, SMD | 0402(1005) | Cap
D1, D2, D3, D5, D6, D7 | OSRAM | LG L29K-F2J1-24 | 6 | Digikey | 475-1193-1-ND | LED, 1.7V, 0.02A, Green, 570nm, diffused, 0603, SMD | 0603(1608) LED | Green
L1, L2 | Taiyo Yuden | MCKK1608T1R0MN | 2 | Digikey | 587-5973-1-ND | Inductor, Shielded, 1u, 1.3A, 0.123 Ohms, 0603, SMD | 0603(1608) | Inductor
L3 | TDK | MMZ2012Y121B | 1 | Digikey | 445-2196-1-ND | Inductor, Ferrite Bead, 0.8A, 120 Ohm at 100MHz, Effective from 80MHz To 400MHz, Y Material, 0805, SMD | 0805(2012) | Ferrite Bead Y
P3 | Amphenol FCI | 10118192-0002LF | 1 | Digikey | 609-5379-1-ND | Connector, USB, 5 Positions, Female, 0.026" Spacing, 1.8A, 100V, USB - micro B USB 2.0 Receptacle Connector 5 Position Surface Mount, Right Angle, Without Flange, SMD | USB Micro B ZX62 | Micro USB
P7 | Prec-Dip | 811-SS-003-30-002101 | 1 | DigiKey | 1212-1561-ND | | POGO_PIN S_3 | Pogo Pins
R1, R4, R5, R6, R9, R10, R11 | Yageo | RC0402FR-07100RL | 7 | Digikey | 311-100LRCT-ND | Resistor, Thick Film, 100 Ohms, 0.0625W, 1% Tol, 100V, 0402, SMD | 0402(1005) | Res1
R2, R3, R7 | Stackpole Electronics | RMCF0402FT10K0 | 3 | Digikey | RMCF0402FT10K0CT-ND | Resistor, Thick Film, 10k Ohms, 0.0625W, 1% Tol, 100V, 0402, SMD | 0402(1005) | 0.1% 25ppm
R8 | Panasonic | ERJ-3EKF1692V | 1 | Digikey | P16.9KHCT-ND | Resistor, Thick Film, 16.9k Ohms, 0.1W, 1% Tol, 0603, SMD | 0603(1608) | Res1
R12, R13, R14, R15 | Yageo | RC0402FR-074K99L | 4 | Digikey | 311-4.99KLRCT-ND | Resistor, Thick Film, 4.99k Ohms, 0.063W, 1% Tol, RES SMD 4.99K OHM 1% 1/16W 0402, 0402, SMD | 0402(1005) | Res1
2019-07-21 | 1/2 | Probe-Scope v1.0.0
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
